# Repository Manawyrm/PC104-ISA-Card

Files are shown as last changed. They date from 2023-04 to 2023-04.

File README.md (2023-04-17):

# PC104-ISA-Card

Adapter for connecting a PC104 computer to a 16-bit ISA backplane.  
Power can be supplied from the backplane or from the PC104 module itself.  
DMA and IRQs are supported. Optional support for power filtering capacitors on the PCB is present.

 


## Status

RevA is fully functional and works well.

## Attribution

[sur5r](https://github.com/sur5r) - Schematic, mechanical design, initial PCB layout  

[Manawyrm](https://github.com/Manawyrm) - PCB layout/routing

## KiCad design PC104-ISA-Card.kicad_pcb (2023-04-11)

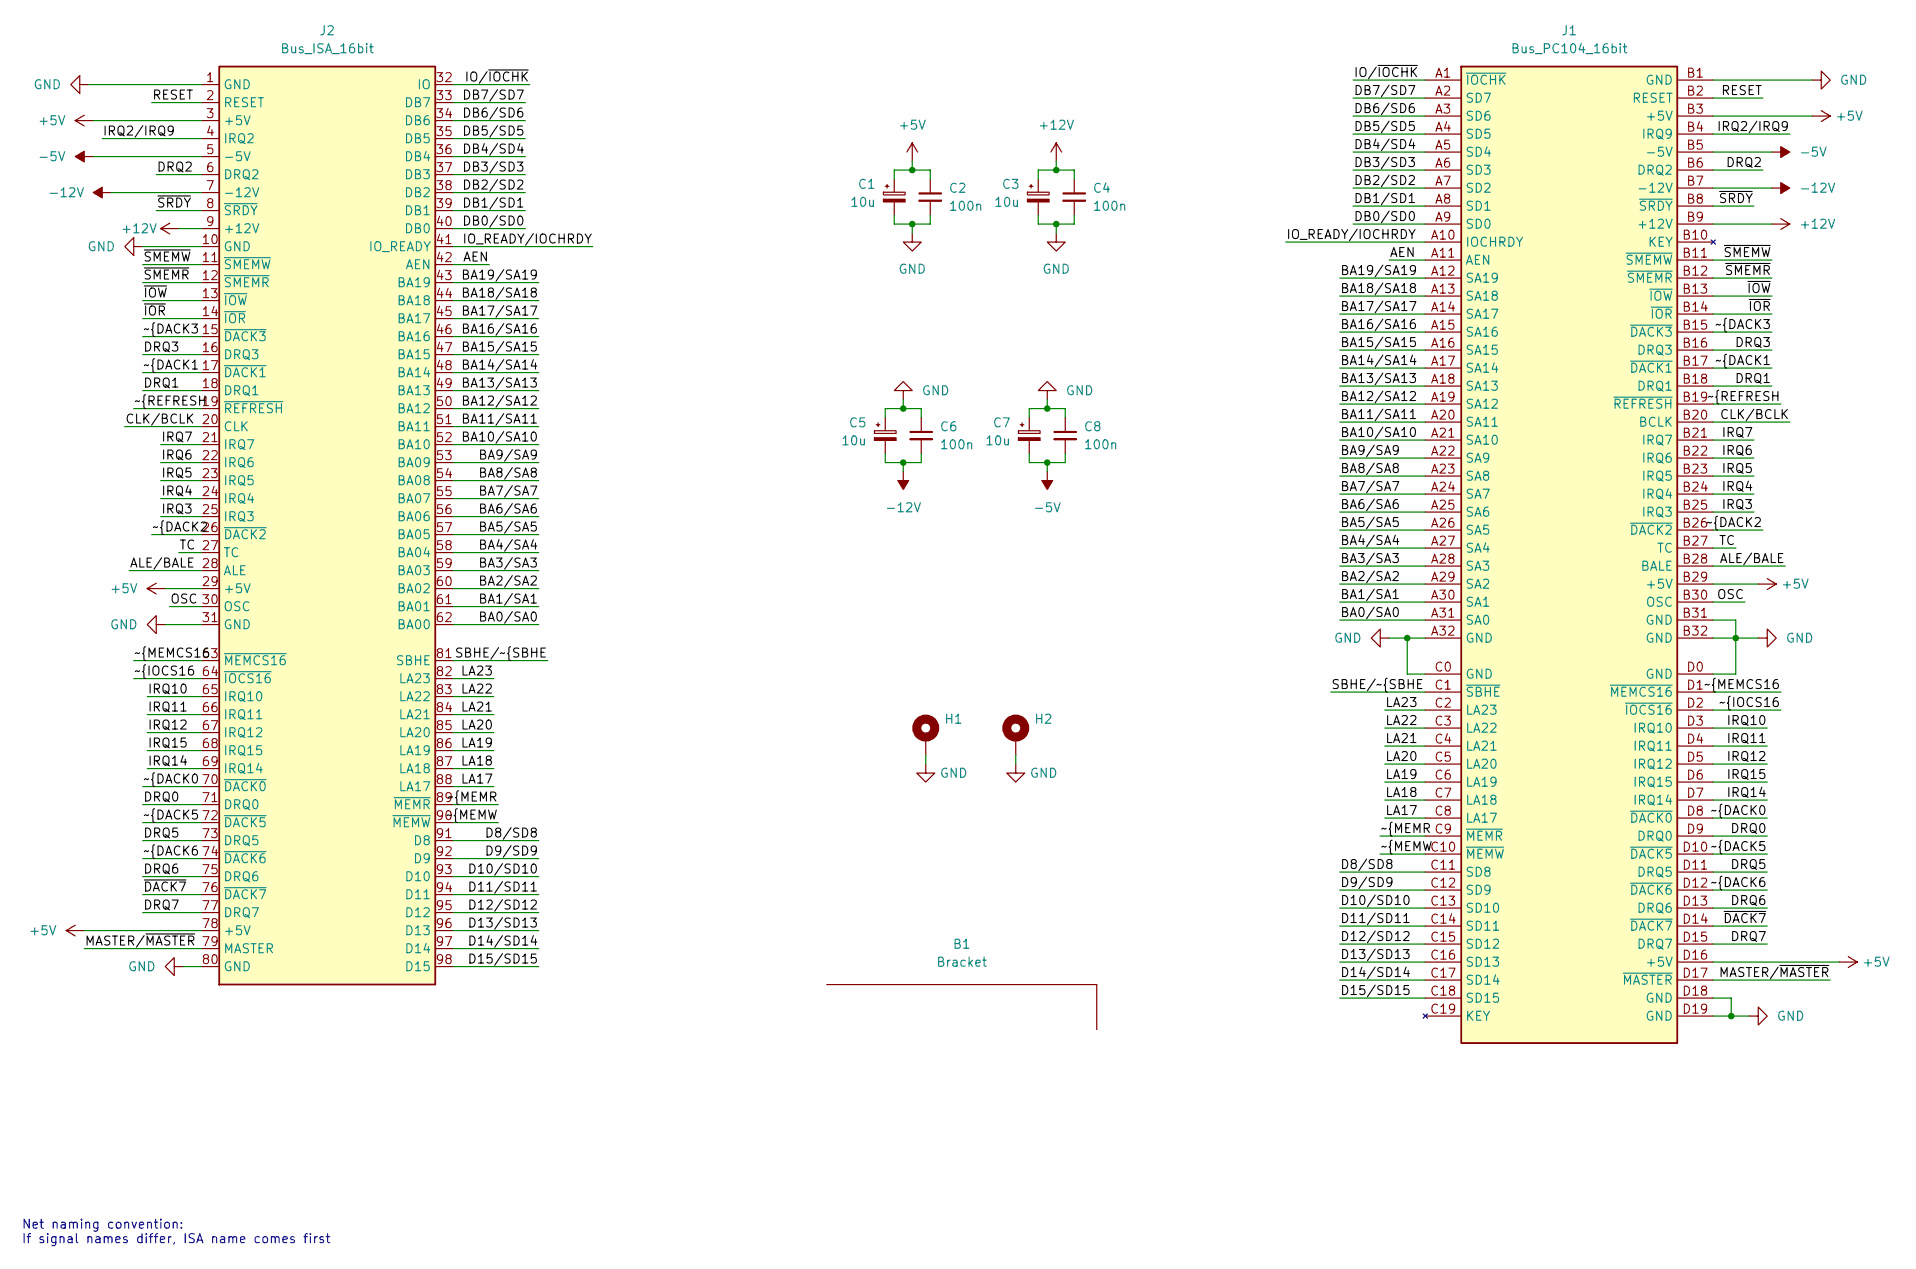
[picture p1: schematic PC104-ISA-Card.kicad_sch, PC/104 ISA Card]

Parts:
B1: Bracket; MPN 9202
C1, C3, C5, C7: 10u; CP_EIA-7343-15_Kemet-W
C2, C4, C6, C8: 100n; C_0603_1608Metric
H1, H2: MountingHole_3.2mm_M3_Pad_Via
J1: Bus_PC104_16bit; PC104_16bit
J2: Bus_ISA_16bit; BUS_AT

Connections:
+5V: C1.1, C2.1, J1.B3 (+5V), J1.B29 (+5V), J1.D16 (+5V), J2.3 (+5V), J2.29 (+5V), J2.78 (+5V)
+12V: C3.1, C4.1, J1.B9 (+12V), J2.9 (+12V)
-5V: C7.2, C8.2, J1.B5 (-5V), J2.5 (-5V)
-12V: C5.2, C6.2, J1.B7 (-12V), J2.7 (-12V)
/AEN: J1.A11 (AEN), J2.42 (AEN)
/ALE/BALE: J1.B28 (BALE), J2.28 (ALE)
/BA0/SA0: J1.A31 (SA0), J2.62 (BA00)
/BA1/SA1: J1.A30 (SA1), J2.61 (BA01)
/BA2/SA2: J1.A29 (SA2), J2.60 (BA02)
/BA3/SA3: J1.A28 (SA3), J2.59 (BA03)
/BA4/SA4: J1.A27 (SA4), J2.58 (BA04)
/BA5/SA5: J1.A26 (SA5), J2.57 (BA05)
/BA6/SA6: J1.A25 (SA6), J2.56 (BA06)
/BA7/SA7: J1.A24 (SA7), J2.55 (BA07)
/BA8/SA8: J1.A23 (SA8), J2.54 (BA08)
/BA9/SA9: J1.A22 (SA9), J2.53 (BA09)
/BA10/SA10: J1.A21 (SA10), J2.52 (BA10)
/BA11/SA11: J1.A20 (SA11), J2.51 (BA11)
/BA12/SA12: J1.A19 (SA12), J2.50 (BA12)
/BA13/SA13: J1.A18 (SA13), J2.49 (BA13)
/BA14/SA14: J1.A17 (SA14), J2.48 (BA14)
/BA15/SA15: J1.A16 (SA15), J2.47 (BA15)
/BA16/SA16: J1.A15 (SA16), J2.46 (BA16)
/BA17/SA17: J1.A14 (SA17), J2.45 (BA17)
/BA18/SA18: J1.A13 (SA18), J2.44 (BA18)
/BA19/SA19: J1.A12 (SA19), J2.43 (BA19)
/CLK/BCLK: J1.B20 (BCLK), J2.20 (CLK)
/D8/SD8: J1.C11 (SD8), J2.91 (D8)
/D9/SD9: J1.C12 (SD9), J2.92 (D9)
/D10/SD10: J1.C13 (SD10), J2.93 (D10)
/D11/SD11: J1.C14 (SD11), J2.94 (D11)
/D12/SD12: J1.C15 (SD12), J2.95 (D12)
/D13/SD13: J1.C16 (SD13), J2.96 (D13)
/D14/SD14: J1.C17 (SD14), J2.97 (D14)
/D15/SD15: J1.C18 (SD15), J2.98 (D15)
/DB0/SD0: J1.A9 (SD0), J2.40 (DB0)
/DB1/SD1: J1.A8 (SD1), J2.39 (DB1)
/DB2/SD2: J1.A7 (SD2), J2.38 (DB2)
/DB3/SD3: J1.A6 (SD3), J2.37 (DB3)
/DB4/SD4: J1.A5 (SD4), J2.36 (DB4)
/DB5/SD5: J1.A4 (SD5), J2.35 (DB5)
/DB6/SD6: J1.A3 (SD6), J2.34 (DB6)
/DB7/SD7: J1.A2 (SD7), J2.33 (DB7)
/DRQ0: J1.D9 (DRQ0), J2.71 (DRQ0)
/DRQ1: J1.B18 (DRQ1), J2.18 (DRQ1)
/DRQ2: J1.B6 (DRQ2), J2.6 (DRQ2)
/DRQ3: J1.B16 (DRQ3), J2.16 (DRQ3)
/DRQ5: J1.D11 (DRQ5), J2.73 (DRQ5)
/DRQ6: J1.D13 (DRQ6), J2.75 (DRQ6)
/DRQ7: J1.D15 (DRQ7), J2.77 (DRQ7)
/IO_READY/IOCHRDY: J1.A10 (IOCHRDY), J2.41 (IO_READY)
/IO/~IOCHK: J1.A1 (~IOCHK), J2.32 (IO)
/IRQ2/IRQ9: J1.B4 (IRQ9), J2.4 (IRQ2)
/IRQ3: J1.B25 (IRQ3), J2.25 (IRQ3)
/IRQ4: J1.B24 (IRQ4), J2.24 (IRQ4)
/IRQ5: J1.B23 (IRQ5), J2.23 (IRQ5)
/IRQ6: J1.B22 (IRQ6), J2.22 (IRQ6)
/IRQ7: J1.B21 (IRQ7), J2.21 (IRQ7)
/IRQ10: J1.D3 (IRQ10), J2.65 (IRQ10)
/IRQ11: J1.D4 (IRQ11), J2.66 (IRQ11)
/IRQ12: J1.D5 (IRQ12), J2.67 (IRQ12)
/IRQ14: J1.D7 (IRQ14), J2.69 (IRQ14)
/IRQ15: J1.D6 (IRQ15), J2.68 (IRQ15)
/LA17: J1.C8 (LA17), J2.88 (LA17)
/LA18: J1.C7 (LA18), J2.87 (LA18)
/LA19: J1.C6 (LA19), J2.86 (LA19)
/LA20: J1.C5 (LA20), J2.85 (LA20)
/LA21: J1.C4 (LA21), J2.84 (LA21)
/LA22: J1.C3 (LA22), J2.83 (LA22)
/LA23: J1.C2 (LA23), J2.82 (LA23)
/MASTER/~MASTER: J1.D17 (~MASTER), J2.79 (MASTER)
/OSC: J1.B30 (OSC), J2.30 (OSC)
/RESET: J1.B2 (RESET), J2.2 (RESET)
/SBHE/~SBHE: J1.C1 (~SBHE), J2.81 (SBHE)
/TC: J1.B27 (TC), J2.27 (TC)
/~DACK0: J1.D8 (~DACK0), J2.70 (~DACK0)
/~DACK1: J1.B17 (~DACK1), J2.17 (~DACK1)
/~DACK2: J1.B26 (~DACK2), J2.26 (~DACK2)
/~DACK3: J1.B15 (~DACK3), J2.15 (~DACK3)
/~DACK5: J1.D10 (~DACK5), J2.72 (~DACK5)
/~DACK6: J1.D12 (~DACK6), J2.74 (~DACK6)
/~DACK7: J1.D14 (~DACK7), J2.76 (~DACK7)
/~IOCS16: J1.D2 (~IOCS16), J2.64 (~IOCS16)
/~IOR: J1.B14 (~IOR), J2.14 (~IOR)
/~IOW: J1.B13 (~IOW), J2.13 (~IOW)
/~MEMCS16: J1.D1 (~MEMCS16), J2.63 (~MEMCS16)
/~MEMR: J1.C9 (~MEMR), J2.89 (~MEMR)
/~MEMW: J1.C10 (~MEMW), J2.90 (~MEMW)
/~REFRESH: J1.B19 (~REFRESH), J2.19 (~REFRESH)
/~SMEMR: J1.B12 (~SMEMR), J2.12 (~SMEMR)
/~SMEMW: J1.B11 (~SMEMW), J2.11 (~SMEMW)
/~SRDY: J1.B8 (~SRDY), J2.8 (~SRDY)
GND: C1.2, C2.2, C3.2, C4.2, C5.1, C6.1, C7.1, C8.1, H1.1, H2.1, J1.A32 (GND), J1.B1 (GND), J1.B31 (GND), J1.B32 (GND), J1.C0 (GND), J1.D0 (GND), J1.D18 (GND), J1.D19 (GND), J2.1 (GND), J2.10 (GND), J2.31 (GND), J2.80 (GND)

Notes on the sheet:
Net naming convention: If signal names differ, ISA name comes first

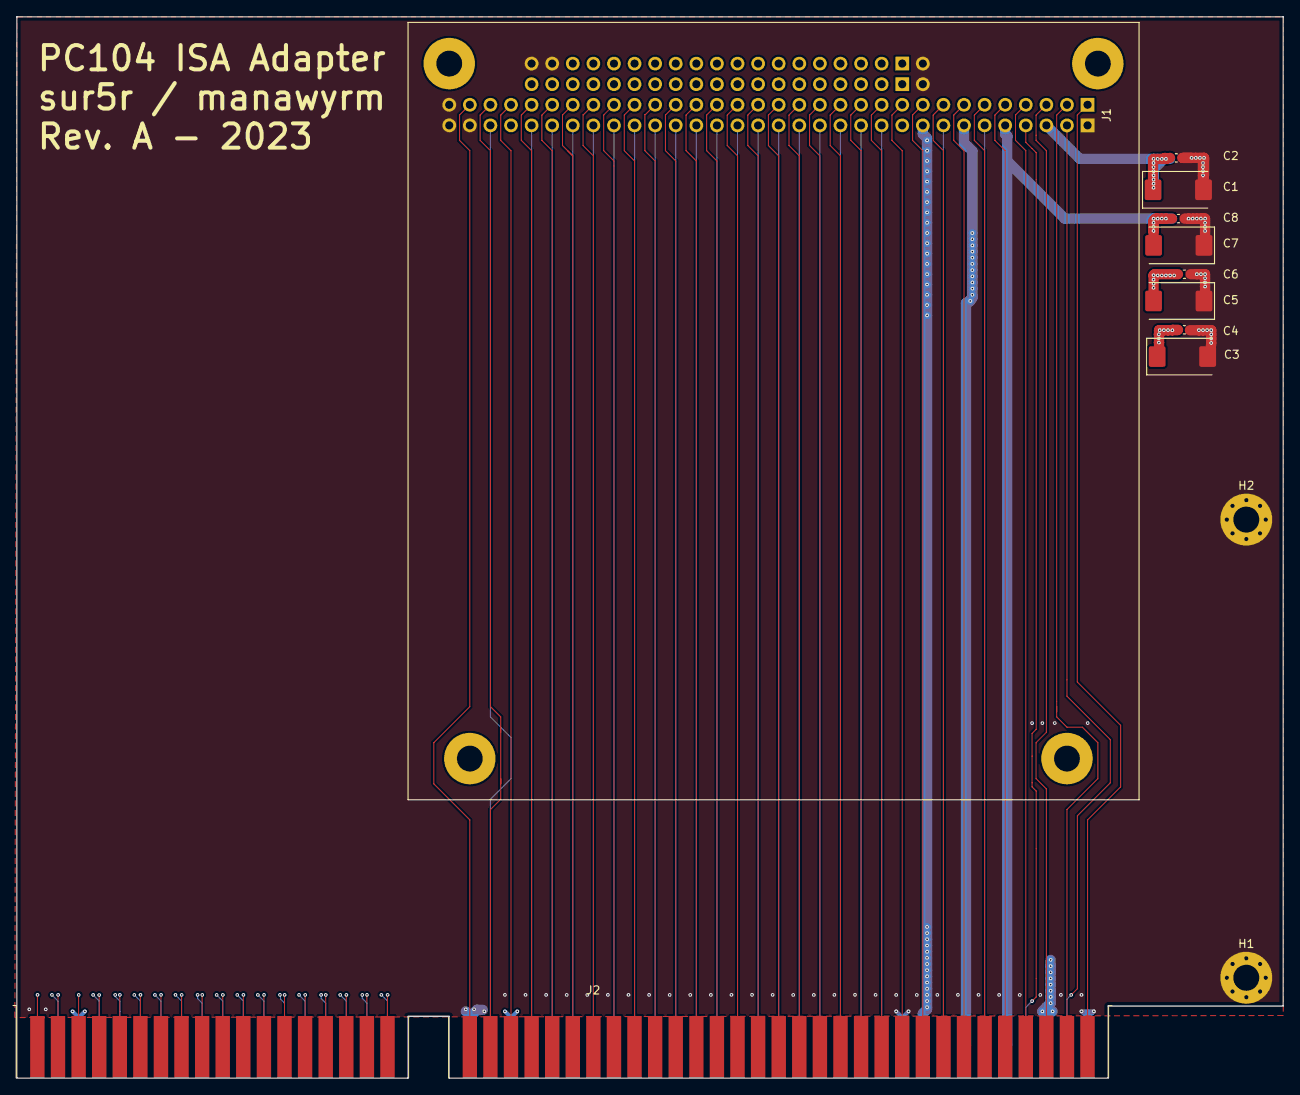
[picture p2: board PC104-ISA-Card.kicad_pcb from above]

Board: 4 copper layers, 156.2 x 130.9 mm, 12 parts (0 on the bottom side), 93 nets.

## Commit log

2023-03-04 Move mounting holes to correct place for Keystone 9202
    [PC104-ISA-Card.kicad_pcb]
2023-03-04 Reduce board height
    [PC104-ISA-Card.kicad_pcb]
2023-03-04 Add bracket symbol
2023-03-04 Fix pin number typo
2023-03-04 Preliminary schematic
    [PC104-ISA-Card.kicad_sch]
2023-03-04 Fix SRDY pin details
    [PC104-ISA-Card.kicad_sch]
2023-03-26 Layout WIP
    [PC104-ISA-Card.kicad_pcb]
2023-03-27 Added layout
    [PC104-ISA-Card.kicad_pcb, PC104-ISA-Card.kicad_sch]
2023-03-27 Fix ISA slot grounding
    [PC104-ISA-Card.kicad_pcb]
2023-04-11 Add gerbers
    [PC104-ISA-Card-B_Cu.gbr, PC104-ISA-Card-B_Mask.gbr, PC104-ISA-Card-B_Paste.gbr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]
